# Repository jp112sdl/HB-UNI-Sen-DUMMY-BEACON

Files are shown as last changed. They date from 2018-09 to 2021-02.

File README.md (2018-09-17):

# HB-UNI-Sen-DUMMY-BEACON
**Dummy-Device zum Vermeiden von "Kommunikation gestört"-Servicemeldungen von bis zu 8 inaktiven HomeMatic-Geräten (nur HM-RF, kein HmIP / Wired).**<br/>

Die ist z.B. sehr nützlich bei saisonal verwendeten Geräten, die in Programmen, Diagrammen etc. verwendet, jedoch z.B. in Wintermonaten nicht genutzt werden.
Denn ein Ablernen der Geräte während der Nutzungspausen würde bedeuten, dass Programme nach dem erneuten Anlernen wieder bearbeitet werden müssten.

Es erfolgt:
 - eine automatische Aussendung zyklischer Telegramme an die CCU (bei Sensoren)
 - eine Quittung (Ack) von Steuerbefehlen der CCU (bei Aktoren)
 
_Wird ein Telegramm des "echten" Gerätes empfangen, so wird das Aussenden der Fake-Telegramme automatisch deaktiviert, um Kollisionen / Fehlverhalten zu vermeiden._
 
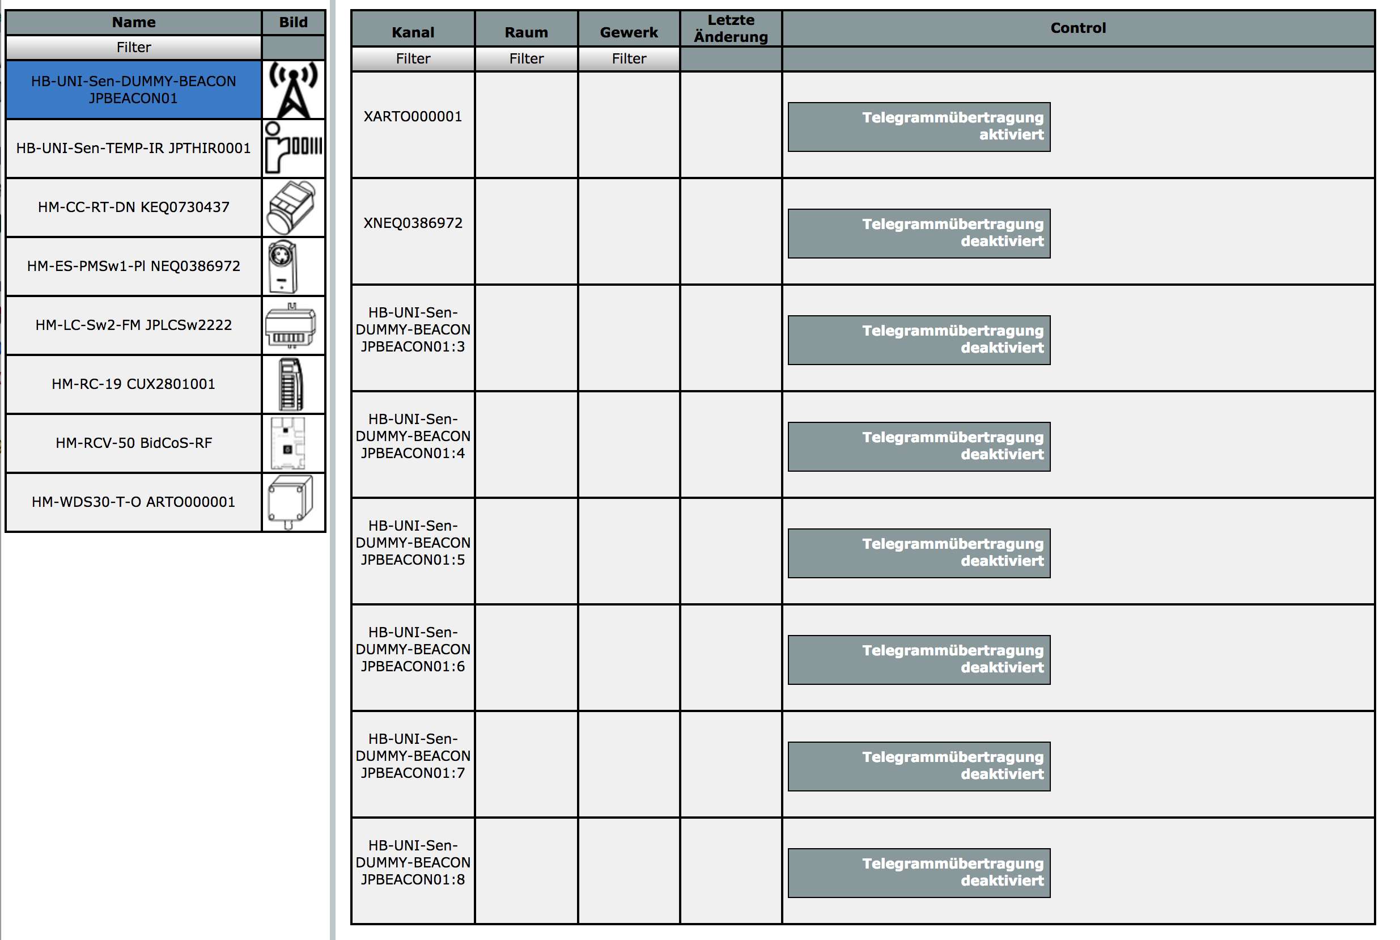
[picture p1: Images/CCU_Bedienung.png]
bedienung
 

## Hardware
### Bauteile
 - 1x Arduino Pro Mini (3.3V 8MHz)
 - 1x CC1101 Funkmodul 868MHz
 - 1x FTDI Adapter
 - 1x Taster
 - 1x Widerstand 330Ohm
 - 1x LED
 
### Verdrahtung
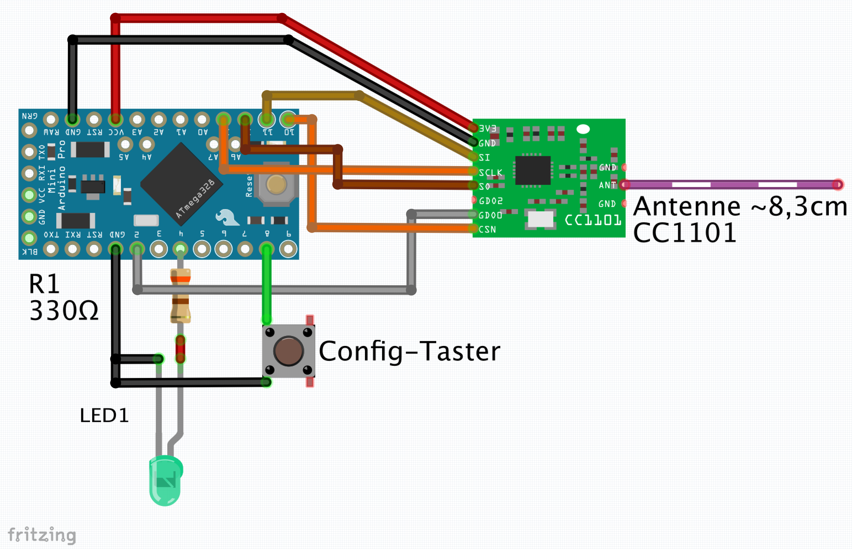
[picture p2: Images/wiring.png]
wiring


Die Stromversorgung erfolgt indealerweise aus einem 5V-Steckernetzteil und wird an **RAW** (+) sowie **GND** (-) des Pro Mini angeschlossen.

## Software
### Arduino IDE
- Arduino IDE [herunterladen](https://www.arduino.cc/en/Main/Software) und installieren
- AskSinPP Bibliothek als [ZIP herunterladen](https://github.com/pa-pa/AskSinPP/archive/master.zip) 
- notwendige Bibliotheken in der Arduino IDE hinzufügen:
  - Sketch -> Bibliothek einbinden -> .ZIP-Bibliothek hinzufügen
    - heruntergeladene AskSinPP Bibliothek ZIP-Datei auswählen
  - Sketch -> Bibliothek einbinden -> Bibliotheken verwalten
    - im Suchfeld folgende Bibliotheken suchen und installieren:
      - EnableInterrupt
      - Low-Power
 - Board einstellen:
   - Board: `Arduino Pro or Pro Mini`
   - Prozessor: `ATmega328P (3.3V, 8 MHz)`
   - Port: `COM-Port` des FTDI Adapters <br>
 - Sketch öffnen. (Die 3 Dateien [HB-UNI-Sen-DUMMY-BEACON.ino](https://raw.githubusercontent.com/jp112sdl/HB-UNI-Sen-DUMMY-BEACON/master/HB-UNI-Sen-DUMMY-BEACON.ino), [HB_Device.h](https://raw.githubusercontent.com/jp112sdl/HB-UNI-Sen-DUMMY-BEACON/master/HB_Device.h) und [HB_MultiChannelDevice.h](https://raw.githubusercontent.com/jp112sdl/HB-UNI-Sen-DUMMY-BEACON/master/HB_MultiChannelDevice.h) müssen sich in einem gemeinsamen Verzeichnis befinden.)
            
- Sketch hochladen:
  - Sketch
    - Hochladen

## HomeMatic
### Addon installieren
Damit das Gerät von der CCU erkannt und unterstützt wird, ist es erforderlich, das [JP-HB-Devices-addon](https://github.com/jp112sdl/JP-HB-Devices-addon) zu installieren.<br/>Es wird **mindestens Version 1.18** benötigt.

### Anlernen an HomeMatic
Das Anlernen erfolgt nach Installation des Addons wie man es von anderen HomeMatic-Geräten gewohnt ist:
- Geräte anlernen -> HM-Gerät anlernen klicken
- **Config-Taster** am Arduino Pro Mini **kurz** drücken
- das neue Gerät erscheint anschließend im Posteingang

### Konfiguration
Damit das Dummy-Device weiß, wessen Telegramme es nun ersetzen soll, müssen die **Adressen** _(Achtung: nicht die Seriennummern!)_ der Geräte im Dummy-Device hinterlegt werden.
<br/>
_Hintergrund-Info: 
Anhand der Seriennummer wird ein HomeMatic Gerät nicht im Funkprotokoll identifiziert. Dies geschieht ausschließlich über die Geräteadresse. Die Adresse (RF_ADDRESS) eines HomeMatic-Geräts ist leider nicht ohne Umwege in der WebUI ersichtlich.
Sie lässt sich beispielsweise als hexadezimalwert dem Device-File im Dateisystem `/etc/config/rfd/<SERIAL.dev>` entnehmen:<br/>

<br/>_

Um das Hinterlegen der gewünschten Adressen weitestgehend zu automatisieren ist wie folgt vorzugehen:<br/><br/>
**1.** In den Geräteeinstellungen des Dummy-Device ist ein Kanal umzubenennen.<br/>
Der Kanalname muss beginnen mit **X** gefolgt von der Seriennummer, des HomeMatic Geräts, das abgebildet werden soll.<br/>
Beispiel:<br/>
 - das HomeMatic-Gerät hat die Seriennummer: **NEQ0386972**
 - der Kanalname des Dummy-Device muss lauten: **XNEQ0386972**

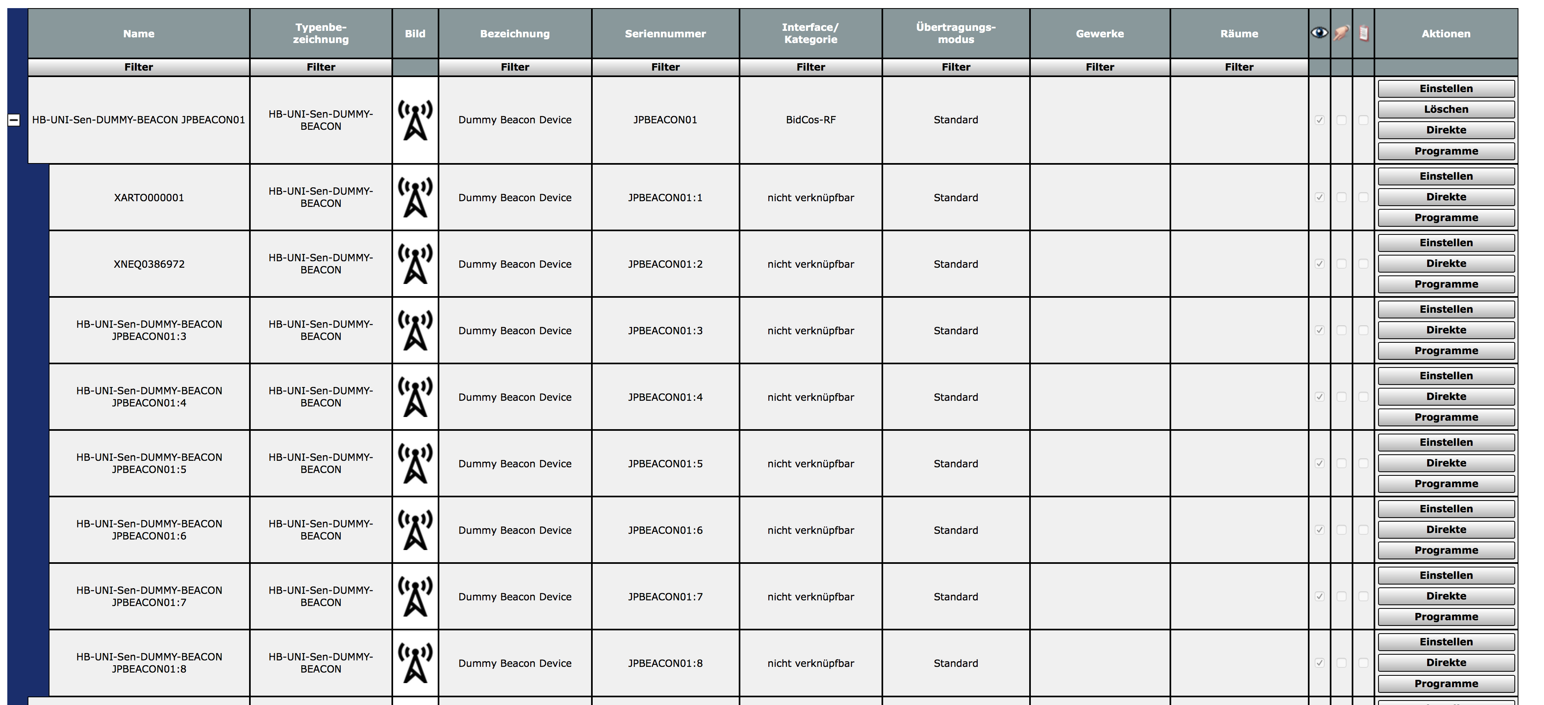
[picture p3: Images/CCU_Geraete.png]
gerate

 <br/>
 
 **2.** Ausführen des [Parametrierungsskripts](https://raw.githubusercontent.com/jp112sdl/HB-UNI-Sen-DUMMY-BEACON/master/additional/ccu_script.txt) auf der CCU.<br/>
(Sollte die Seriennummer des Dummy-Device *nicht* **JPBEACON01** lauten, so ist diese im Skript entpsrechend zu ändern (`string FAKEDEV = "JPBEACON01";`).)
<br/>
Durch Ausführen des Skripts werden nun die Adressen der Geräte ausgelesen und zum Dummy-Device übertragen.

**3.** Einstellungen<br/>
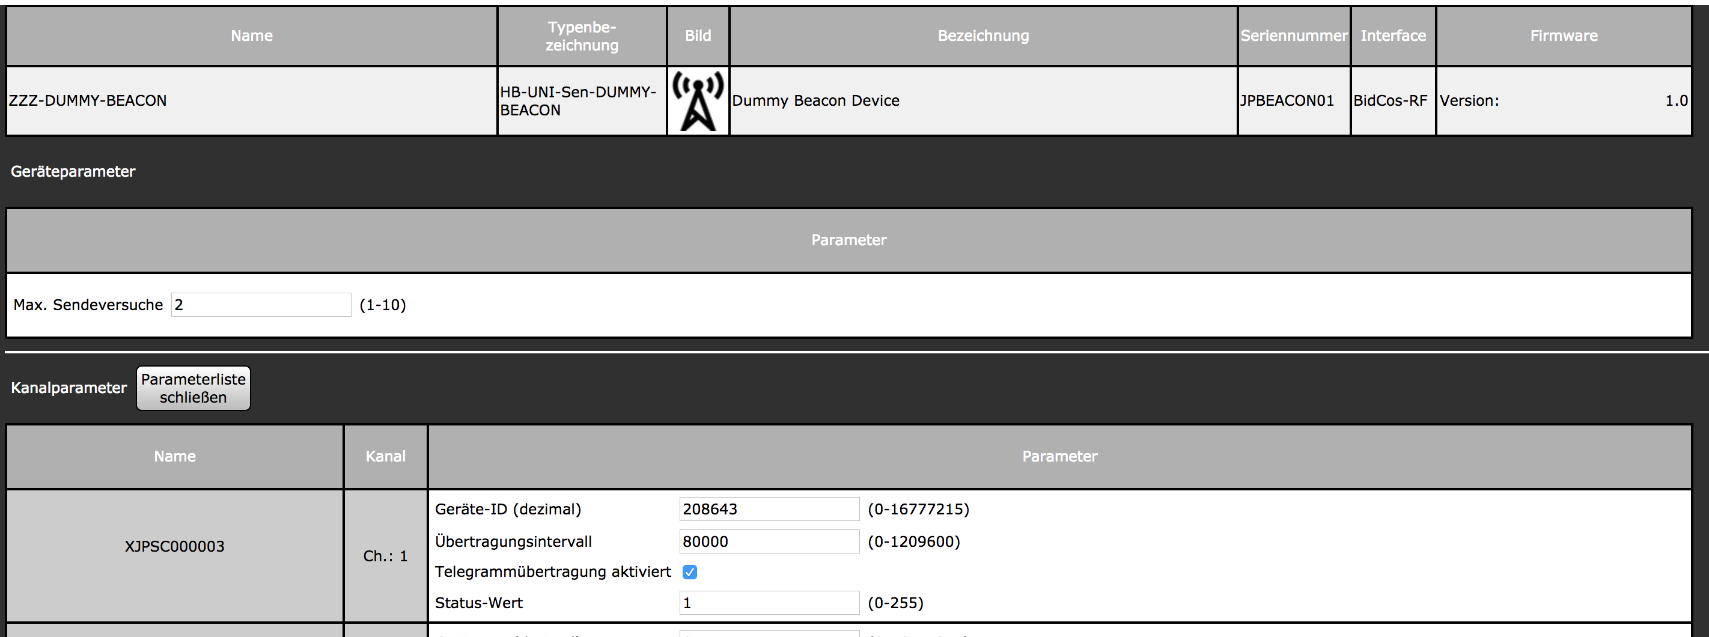
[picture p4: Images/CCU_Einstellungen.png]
einstellungen

<br/>
In den Einstellungen können Parameter
 - für das Gerät
   - Max. Sendeversuche: Anzahl der Sendeversuche bei bidirektionalen Nachrichten
 - je Kanal (also je emuliertem Gerät)
   - Geräte-ID: RF-Adresse; hier dezimal! (wird vom Skript gesetzt)
   - Übertragungsintervall: alle x Sekunden wird ein zyklisches Telegramm gesendet (nur bei Sensoren, bei Aktoren (außer HM-ES-PMSw1-xxx) auf 0 lassen!); die eingegebene Zeit muss kleiner sein als der von HomeMatic erwartete Wert (siehe unten stehende Tabelle)
   - Telegrammübertragung aktiviert: Dummy-Nachrichten werden für dieses Gerät generiert
   - Status-Wert: z.B. bei Fensterkontakt "geschlossen" (0) oder "offen" (1) übertragen
 
 festgelegt werden.

**4.** Betrieb<br/>
Unter "Status und Bedienung"->"Geräte" ist eine Übersicht der aktivierten Kanäle zu sehen.<br/>
bedienung
<br/><br/>
**Achtung:** Der Status der Telegrammübertragung (aktiviert / deaktiviert) muss nicht zwingend der Einstellung wie unter **3.** festgelegt entsprechen!<br/>
Es wird der tatsächliche Status wiedergegeben. Ist z.B. ein Kanal in **3.** aktiviert und es wird jedoch ein Funktelegramm vom "echten" HomeMatic-Gerät empfangen, wird der Kanal in der Übersicht deaktiviert!

**Diese README ist garantiert nicht vollständig! Bei Unklarheiten bitte ein Issue erstellen.**

#### CYCLIC_TIMEOUT Werte der HomeMatic-Geräte:

| Device Type | Timeout | Model ID |
|---|---|---|
| HM-CC-RT-DN | 600 | 0x0095 | 
| HM-CC-RT-DN-BoM | 552 | 0x00bd | 
| HM-CC-SCD | 88200 | 0x0056 | 
| HM-CC-TC | 600 | 0x0039 | 
| HM-CC-VD | 3600 | 0x003a | 
| HM-ES-PMSw1-DR | 600 | 0x00ea | 
| HM-ES-PMSw1-Pl | 600 | 0x00ac | 
| HM-ES-PMSw1-Pl-DN-R1 | 600 | 0x00d7 | 
| HM-ES-PMSw1-Pl-DN-R2 | 600 | 0x00e2 | 
| HM-ES-PMSw1-Pl-DN-R3 | 600 | 0x00e3 | 
| HM-ES-PMSw1-Pl-DN-R4 | 600 | 0x00e4 | 
| HM-ES-PMSw1-Pl-DN-R5 | 600 | 0x00e5 | 
| HM-ES-PMSw1-S | 600 | 0x00f6 | 
| HM-ES-TX-WM | 600 | 0x00de | 
| HM-SCI-3-FM | 88200 | 0x005f | 
| HM-Sec-MDIR | 1200 | 0x004a | 
| HM-Sec-MDIR-2 | 1200 | 0x00c0 | 
| HM-Sec-MDIR-3 | 1200 | 0x00f7 | 
| HM-Sec-RHS | 88200 | 0x0030 | 
| HM-Sec-SC | 88200 | 0x002f | 
| HM-Sec-SC-2 | 88200 | 0x00b1 | 
| HM-Sec-SCo | 10000 | 0x00c7 | 
| HM-Sec-SD | 1209600 | 0x0042 | 
| HM-Sec-SD-2 | 259200 | 0x00aa | 
| HM-Sec-TiS | 88200 | 0x0043 | 
| HM-Sec-WDS | 88200 | 0x0045 | 
| HM-Sec-WDS-2 | 88200 | 0x00b2 | 
| HM-Sen-LI-O | 88200 | 0x00fd | 
| HM-Sen-RD-O | 88200 | 0x00a7 | 
| HM-Sen-Wa-Od | 88200 | 0x009f | 
| HM-TC-IT-WM-W-EU | 600 | 0x00ad | 
| HM-WDS10-TH-O | 600 | 0x003d | 
| HM-WDS100-C6-O | 600 | 0x0040 | 
| HM-WDS100-C6-O-2 | 600 | 0x00ae | 
| HM-WDS20-TH-O | 600 | 0x003c | 
| HM-WDS30-OT2-SM | 40000 | 0x00a8 | 
| HM-WDS30-OT2-SM-2 | 40000 | 0x0102 | 
| HM-WDS30-T-O | 600 | 0x000f | 
| HM-WDS40-TH-I | 600 | 0x003f | 
| HM-WDS40-TH-I-2 | 600 | 0x00bc |

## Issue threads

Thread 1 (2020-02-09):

Fehlermeldungen beim Kompilieren

MathiasJZ, 2020-02-09:
Wenn ich die Firmware bei Arduino-Ide kompiliere bekomme ich immer die gleiche Fehlermeldung:

`Arduino: 1.8.11 (Windows 10), Board: "Arduino Pro or Pro Mini, ATmega328P (3.3V, 8 MHz)

C:\Program Files (x86)\arduino-1.8.11\arduino-builder -dump-prefs -logger=machine -hardware C:\Program Files (x86)\arduino-1.8.11\hardware -hardware C:\Users\mathi\AppData\Local\Arduino15\packages -tools C:\Program Files (x86)\arduino-1.8.11\tools-builder -tools C:\Program Files (x86)\arduino-1.8.11\hardware\tools\avr -tools C:\Users\mathi\AppData\Local\Arduino15\packages -built-in-libraries C:\Program Files (x86)\arduino-1.8.11\libraries -libraries C:\Users\mathi\OneDrive\Documents\Arduino\libraries -fqbn=arduino:avr:pro:cpu=8MHzatmega328 -ide-version=10811 -build-path C:\Users\mathi\AppData\Local\Temp\arduino_build_962732 -warnings=none -build-cache C:\Users\mathi\AppData\Local\Temp\arduino_cache_655553 -prefs=build.warn_data_percentage=75 -prefs=runtime.tools.avr-gcc.path=C:\Program Files (x86)\arduino-1.8.11\hardware\tools\avr -prefs=runtime.tools.avr-gcc-7.3.0-atmel3.6.1-arduino5.path=C:\Program Files (x86)\arduino-1.8.11\hardware\tools\avr -prefs=runtime.tools.arduinoOTA.path=C:\Program Files (x86)\arduino-1.8.11\hardware\tools\avr -prefs=runtime.tools.arduinoOTA-1.3.0.path=C:\Program Files (x86)\arduino-1.8.11\hardware\tools\avr -prefs=runtime.tools.avrdude.path=C:\Program Files (x86)\arduino-1.8.11\hardware\tools\avr -prefs=runtime.tools.avrdude-6.3.0-arduino17.path=C:\Program Files (x86)\arduino-1.8.11\hardware\tools\avr -verbose M:\HB-UNI-Sen-DUMMY-BEACON-master\HB-UNI-Sen-DUMMY-BEACON-master\HB-UNI-Sen-DUMMY-BEACON\HB-UNI-Sen-DUMMY-BEACON.ino
C:\Program Files (x86)\arduino-1.8.11\arduino-builder -compile -logger=machine -hardware C:\Program Files (x86)\arduino-1.8.11\hardware -hardware C:\Users\mathi\AppData\Local\Arduino15\packages -tools C:\Program Files (x86)\arduino-1.8.11\tools-builder -tools C:\Program Files (x86)\arduino-1.8.11\hardware\tools\avr -tools C:\Users\mathi\AppData\Local\Arduino15\packages -built-in-libraries C:\Program Files (x86)\arduino-1.8.11\libraries -libraries C:\Users\mathi\OneDrive\Documents\Arduino\libraries -fqbn=arduino:avr:pro:cpu=8MHzatmega328 -ide-version=10811 -build-path C:\Users\mathi\AppData\Local\Temp\arduino_build_962732 -warnings=none -build-cache C:\Users\mathi\AppData\Local\Temp\arduino_cache_655553 -prefs=build.warn_data_percentage=75 -prefs=runtime.tools.avr-gcc.path=C:\Program Files (x86)\arduino-1.8.11\hardware\tools\avr -prefs=runtime.tools.avr-gcc-7.3.0-atmel3.6.1-arduino5.path=C:\Program Files (x86)\arduino-1.8.11\hardware\tools\avr -prefs=runtime.tools.arduinoOTA.path=C:\Program Files (x86)\arduino-1.8.11\hardware\tools\avr -prefs=runtime.tools.arduinoOTA-1.3.0.path=C:\Program Files (x86)\arduino-1.8.11\hardware\tools\avr -prefs=runtime.tools.avrdude.path=C:\Program Files (x86)\arduino-1.8.11\hardware\tools\avr -prefs=runtime.tools.avrdude-6.3.0-arduino17.path=C:\Program Files (x86)\arduino-1.8.11\hardware\tools\avr -verbose M:\HB-UNI-Sen-DUMMY-BEACON-master\HB-UNI-Sen-DUMMY-BEACON-master\HB-UNI-Sen-DUMMY-BEACON\HB-UNI-Sen-DUMMY-BEACON.ino
Using board 'pro' from platform in folder: C:\Program
Using core 'arduino' from platform in folder: C:\Program
Detecting libraries used...
"C:\\Program Files (x86)\\arduino-1.8.11\\hardware\\tools\\avr/bin/avr-g++" -c -g -Os -w -std=gnu++11 -fpermissive -fno-exceptions -ffunction-sections -fdata-sections -fno-threadsafe-statics -Wno-error=narrowing -flto -w -x c++ -E -CC -mmcu=atmega328p -DF_CPU=8000000L -DARDUINO=10811 -DARDUINO_AVR_PRO -DARDUINO_ARCH_AVR "-IC:\\Program Files (x86)\\arduino-1.8.11\\hardware\\arduino\\avr\\cores\\arduino" "-IC:\\Program Files (x86)\\arduino-1.8.11\\hardware\\arduino\\avr\\variants\\eightanaloginputs" "C:\\Users\\mathi\\AppData\\Local\\Temp\\arduino_build_962732\\sketch\\HB-UNI-Sen-DUMMY-BEACON.ino.cpp" -o nul
Alternatives for EnableInterrupt.h: [EnableInterrupt@0.9.7]
ResolveLibrary(EnableInterrupt.h)
  -> candidates: [EnableInterrupt@0.9.7]
"C:\\Program Files (x86)\\arduino-1.8.11\\hardware\\tools\\avr/bin/avr-g++" -c -g -Os -w -std=gnu++11 -fpermissive -fno-exceptions -ffunction-sections -fdata-sections -fno-threadsafe-statics -Wno-error=narrowing -flto -w -x c++ -E -CC -mmcu=atmega328p -DF_CPU=8000000L -DARDUINO=10811 -DARDUINO_AVR_PRO -DARDUINO_ARCH_AVR "-IC:\\Program Files (x86)\\arduino-1.8.11\\hardware\\arduino\\avr\\cores\\arduino" "-IC:\\Program Files (x86)\\arduino-1.8.11\\hardware\\arduino\\avr\\variants\\eightanaloginputs" "-IC:\\Users\\mathi\\OneDrive\\Documents\\Arduino\\libraries\\EnableInterrupt" "C:\\Users\\mathi\\AppData\\Local\\Temp\\arduino_build_962732\\sketch\\HB-UNI-Sen-DUMMY-BEACON.ino.cpp" -o nul
Alternatives for AskSinPP.h: [AskSinPP-master@4.1.2]
ResolveLibrary(AskSinPP.h)
  -> candidates: [AskSinPP-master@4.1.2]
"C:\\Program Files (x86)\\arduino-1.8.11\\hardware\\tools\\avr/bin/avr-g++" -c -g -Os -w -std=gnu++11 -fpermissive -fno-exceptions -ffunction-sections -fdata-sections -fno-threadsafe-statics -Wno-error=narrowing -flto -w -x c++ -E -CC -mmcu=atmega328p -DF_CPU=8000000L -DARDUINO=10811 -DARDUINO_AVR_PRO -DARDUINO_ARCH_AVR "-IC:\\Program Files (x86)\\arduino-1.8.11\\hardware\\arduino\\avr\\cores\\arduino" "-IC:\\Program Files (x86)\\arduino-1.8.11\\hardware\\arduino\\avr\\variants\\eightanaloginputs" "-IC:\\Users\\mathi\\OneDrive\\Documents\\Arduino\\libraries\\EnableInterrupt" "-IC:\\Users\\mathi\\OneDrive\\Documents\\Arduino\\libraries\\AskSinPP-master" "C:\\Users\\mathi\\AppData\\Local\\Temp\\arduino_build_962732\\sketch\\HB-UNI-Sen-DUMMY-BEACON.ino.cpp" -o nul
Alternatives for LowPower.h: [Low-Power-master@1.6]
ResolveLibrary(LowPower.h)
  -> candidates: [Low-Power-master@1.6]
"C:\\Program Files (x86)\\arduino-1.8.11\\hardware\\tools\\avr/bin/avr-g++" -c -g -Os -w -std=gnu++11 -fpermissive -fno-exceptions -ffunction-sections -fdata-sections -fno-threadsafe-statics -Wno-error=narrowing -flto -w -x c++ -E -CC -mmcu=atmega328p -DF_CPU=8000000L -DARDUINO=10811 -DARDUINO_AVR_PRO -DARDUINO_ARCH_AVR "-IC:\\Program Files (x86)\\arduino-1.8.11\\hardware\\arduino\\avr\\cores\\arduino" "-IC:\\Program Files (x86)\\arduino-1.8.11\\hardware\\arduino\\avr\\variants\\eightanaloginputs" "-IC:\\Users\\mathi\\OneDrive\\Documents\\Arduino\\libraries\\EnableInterrupt" "-IC:\\Users\\mathi\\OneDrive\\Documents\\Arduino\\libraries\\AskSinPP-master" "-IC:\\Users\\mathi\\OneDrive\\Documents\\Arduino\\libraries\\Low-Power-master" "C:\\Users\\mathi\\AppData\\Local\\Temp\\arduino_build_962732\\sketch\\HB-UNI-Sen-DUMMY-BEACON.ino.cpp" -o nul
"C:\\Program Files (x86)\\arduino-1.8.11\\hardware\\tools\\avr/bin/avr-g++" -c -g -Os -w -std=gnu++11 -fpermissive -fno-exceptions -ffunction-sections -fdata-sections -fno-threadsafe-statics -Wno-error=narrowing -flto -w -x c++ -E -CC -mmcu=atmega328p -DF_CPU=8000000L -DARDUINO=10811 -DARDUINO_AVR_PRO -DARDUINO_ARCH_AVR "-IC:\\Program Files (x86)\\arduino-1.8.11\\hardware\\arduino\\avr\\cores\\arduino" "-IC:\\Program Files (x86)\\arduino-1.8.11\\hardware\\arduino\\avr\\variants\\eightanaloginputs" "-IC:\\Users\\mathi\\OneDrive\\Documents\\Arduino\\libraries\\EnableInterrupt" "-IC:\\Users\\mathi\\OneDrive\\Documents\\Arduino\\libraries\\AskSinPP-master" "-IC:\\Users\\mathi\\OneDrive\\Documents\\Arduino\\libraries\\Low-Power-master" "C:\\Users\\mathi\\OneDrive\\Documents\\Arduino\\libraries\\AskSinPP-master\\AlarmClock.cpp" -o nul
"C:\\Program Files (x86)\\arduino-1.8.11\\hardware\\tools\\avr/bin/avr-g++" -c -g -Os -w -std=gnu++11 -fpermissive -fno-exceptions -ffunction-sections -fdata-sections -fno-threadsafe-statics -Wno-error=narrowing -flto -w -x c++ -E -CC -mmcu=atmega328p -DF_CPU=8000000L -DARDUINO=10811 -DARDUINO_AVR_PRO -DARDUINO_ARCH_AVR "-IC:\\Program Files (x86)\\arduino-1.8.11\\hardware\\arduino\\avr\\cores\\arduino" "-IC:\\Program Files (x86)\\arduino-1.8.11\\hardware\\arduino\\avr\\variants\\eightanaloginputs" "-IC:\\Users\\mathi\\OneDrive\\Documents\\Arduino\\libraries\\EnableInterrupt" "-IC:\\Users\\mathi\\OneDrive\\Documents\\Arduino\\libraries\\AskSinPP-master" "-IC:\\Users\\mathi\\OneDrive\\Documents\\Arduino\\libraries\\Low-Power-master" "C:\\Users\\mathi\\OneDrive\\Documents\\Arduino\\libraries\\AskSinPP-master\\Globals.cpp" -o nul
"C:\\Program Files (x86)\\arduino-1.8.11\\hardware\\tools\\avr/bin/avr-g++" -c -g -Os -w -std=gnu++11 -fpermissive -fno-exceptions -ffunction-sections -fdata-sections -fno-threadsafe-statics -Wno-error=narrowing -flto -w -x c++ -E -CC -mmcu=atmega328p -DF_CPU=8000000L -DARDUINO=10811 -DARDUINO_AVR_PRO -DARDUINO_ARCH_AVR "-IC:\\Program Files (x86)\\arduino-1.8.11\\hardware\\arduino\\avr\\cores\\arduino" "-IC:\\Program Files (x86)\\arduino-1.8.11\\hardware\\arduino\\avr\\variants\\eightanaloginputs" "-IC:\\Users\\mathi\\OneDrive\\Documents\\Arduino\\libraries\\EnableInterrupt" "-IC:\\Users\\mathi\\OneDrive\\Documents\\Arduino\\libraries\\AskSinPP-master" "-IC:\\Users\\mathi\\OneDrive\\Documents\\Arduino\\libraries\\Low-Power-master" "C:\\Users\\mathi\\OneDrive\\Documents\\Arduino\\libraries\\AskSinPP-master\\HMID.cpp" -o nul
"C:\\Program Files (x86)\\arduino-1.8.11\\hardware\\tools\\avr/bin/avr-g++" -c -g -Os -w -std=gnu++11 -fpermissive -fno-exceptions -ffunction-sections -fdata-sections -fno-threadsafe-statics -Wno-error=narrowing -flto -w -x c++ -E -CC -mmcu=atmega328p -DF_CPU=8000000L -DARDUINO=10811 -DARDUINO_AVR_PRO -DARDUINO_ARCH_AVR "-IC:\\Program Files (x86)\\arduino-1.8.11\\hardware\\arduino\\avr\\cores\\arduino" "-IC:\\Program Files (x86)\\arduino-1.8.11\\hardware\\arduino\\avr\\variants\\eightanaloginputs" "-IC:\\Users\\mathi\\OneDrive\\Documents\\Arduino\\libraries\\EnableInterrupt" "-IC:\\Users\\mathi\\OneDrive\\Documents\\Arduino\\libraries\\AskSinPP-master" "-IC:\\Users\\mathi\\OneDrive\\Documents\\Arduino\\libraries\\Low-Power-master" "C:\\Users\\mathi\\OneDrive\\Documents\\Arduino\\libraries\\AskSinPP-master\\Led.cpp" -o nul
"C:\\Program Files (x86)\\arduino-1.8.11\\hardware\\tools\\avr/bin/avr-g++" -c -g -Os -w -std=gnu++11 -fpermissive -fno-exceptions -ffunction-sections -fdata-sections -fno-threadsafe-statics -Wno-error=narrowing -flto -w -x c++ -E -CC -mmcu=atmega328p -DF_CPU=8000000L -DARDUINO=10811 -DARDUINO_AVR_PRO -DARDUINO_ARCH_AVR "-IC:\\Program Files (x86)\\arduino-1.8.11\\hardware\\arduino\\avr\\cores\\arduino" "-IC:\\Program Files (x86)\\arduino-1.8.11\\hardware\\arduino\\avr\\variants\\eightanaloginputs" "-IC:\\Users\\mathi\\OneDrive\\Documents\\Arduino\\libraries\\EnableInterrupt" "-IC:\\Users\\mathi\\OneDrive\\Documents\\Arduino\\libraries\\AskSinPP-master" "-IC:\\Users\\mathi\\OneDrive\\Documents\\Arduino\\libraries\\Low-Power-master" "C:\\Users\\mathi\\OneDrive\\Documents\\Arduino\\libraries\\AskSinPP-master\\PhaseCut.cpp" -o nul
"C:\\Program Files (x86)\\arduino-1.8.11\\hardware\\tools\\avr/bin/avr-g++" -c -g -Os -w -std=gnu++11 -fpermissive -fno-exceptions -ffunction-sections -fdata-sections -fno-threadsafe-statics -Wno-error=narrowing -flto -w -x c++ -E -CC -mmcu=atmega328p -DF_CPU=8000000L -DARDUINO=10811 -DARDUINO_AVR_PRO -DARDUINO_ARCH_AVR "-IC:\\Program Files (x86)\\arduino-1.8.11\\hardware\\arduino\\avr\\cores\\arduino" "-IC:\\Program Files (x86)\\arduino-1.8.11\\hardware\\arduino\\avr\\variants\\eightanaloginputs" "-IC:\\Users\\mathi\\OneDrive\\Documents\\Arduino\\libraries\\EnableInterrupt" "-IC:\\Users\\mathi\\OneDrive\\Documents\\Arduino\\libraries\\AskSinPP-master" "-IC:\\Users\\mathi\\OneDrive\\Documents\\Arduino\\libraries\\Low-Power-master" "C:\\Users\\mathi\\OneDrive\\Documents\\Arduino\\libraries\\AskSinPP-master\\aes128_dec.cpp" -o nul
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

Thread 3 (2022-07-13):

Device mit mehreren channels

kmbach, 2022-07-13:
Hallo, super Idee! Habe die Hard- und Software problemlos installiert.
Mein Problem:
Ich möchte einen Fenstersensor "ZEL STG RM FFK" (entspricht dem  HM-Sec-SC) damit emulieren. Dieser hat einen Sabotagekontakt der natürlich anspricht, wenn ich die Batterie aus dem Sensor entferne.
Wie läßt sich ein gesczlossener Sabotagekontakt emulieren?
Vielen Dank!
Gruß kmbach

jp112sdl, 2022-07-13:
Vollständige (Info)Messages der verschiedenen Geräte sind nicht vorgesehen

Am einfachsten wäre es, du schließt den Sabotagekontakt mit einem spitzen Gegenstand und nimmst dann die Batterien raus.

kmbach, 2022-08-20:
Vielen Dank für die Info! Das reicht co natürlich aus.

Closed 2022-08-20.

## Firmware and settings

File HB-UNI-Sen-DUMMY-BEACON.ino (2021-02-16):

//- -----------------------------------------------------------------------------------------------------------------------
// AskSin++
// 2016-10-31 papa Creative Commons - http://creativecommons.org/licenses/by-nc-sa/3.0/de/
// 2018-08-30 jp112sdl Creative Commons - http://creativecommons.org/licenses/by-nc-sa/3.0/de/
//- -----------------------------------------------------------------------------------------------------------------------
// compatible to AskSinPP commit b4f6000
// ci-test=yes board=328p aes=no

#define MAX_FAKEDEVICE_COUNT  8

#define EI_NOTEXTERNAL
#include <EnableInterrupt.h>
#include <AskSinPP.h>
#include <LowPower.h>
#include <Register.h>

#define SYS_LED_PIN        4
#define OK_LED_PIN         5
#define ERROR_LED_PIN      6

using namespace as;

struct FakeDeviceInfo {
  HMID FakeDeviceID;

  // known timeouts
  // 552, 600, 1200, 3600, 10000, 259200, 40000, 88200, 259200, 1209600
  uint32_t CyclicTimeout;

  bool     Enabled;
  uint32_t CurrentTick;
};

FakeDeviceInfo fakeDevice[MAX_FAKEDEVICE_COUNT];
StatusLed<ERROR_LED_PIN>  errorLed;
#include "HB_MultiChannelDevice.h"
#define CONFIG_BUTTON_PIN  8
#define PEERS_PER_CHANNEL  1
#define CYCLIC_MSG_TIMEOUT 3600  // seconds between sending information about en-/disabled fake devices to ccu

// define all device properties
const struct DeviceInfo PROGMEM devinfo = {
  {0xF3, 0xFF, 0x00},          // Device ID
  "JPBEACON00",                // Device Serial
  {0xF3, 0xFF},                // Device Model
  0x10,                        // Firmware Version
  0x53,                        // Device Type
  {0x01, 0x01}                 // Info Bytes
};

typedef AskSin<StatusLed<SYS_LED_PIN>, NoBattery, Radio<AvrSPI<10, 11, 12, 13>, 2> > Hal;
Hal hal;
StatusLed<OK_LED_PIN> okLed;

DEFREGISTER(UReg0, MASTERID_REGS, DREG_TRANSMITTRYMAX)
class UList0 : public RegList0<UReg0> {
  public:
    UList0 (uint16_t addr) : RegList0<UReg0>(addr) {}
    void defaults () {
      clear();
      transmitDevTryMax(2);
    }
};

DEFREGISTER(UReg1, 0x01, 0x02, 0x03, 0x04, 0x05, 0x06, 0x07, 0x08)
class UList1 : public RegList1<UReg1> {
  public:
    UList1 (uint32_t addr) : RegList1<UReg1>(addr) {}

    bool FakeDeviceID (HMID value) const {
      uint8_t v[3];
      memcpy(v, &value, 3);
      return this->writeRegister(0x01, v[0] & 0xff) && this->writeRegister(0x02, v[1] & 0xff) && this->writeRegister(0x03, v[2] & 0xff);
    }

    HMID FakeDeviceID () const {
      return { this->readRegister(0x01, 0), this->readRegister(0x02, 0), this->readRegister(0x03, 0) };
    }

    bool CyclicTimeout (uint32_t value) const {
      return this->writeRegister(0x04, (value >> 16) & 0xff) && this->writeRegister(0x05, (value >> 8) & 0xff) && this->writeRegister(0x06, value & 0xff);
    }
    uint32_t CyclicTimeout () const {
      return ((uint32_t)this->readRegister(0x04, 0) << 16) | ((uint32_t)this->readRegister(0x05, 0) << 8) | (uint32_t)this->readRegister(0x06, 0);
    }

    bool FakeDeviceEnabled () const {
      return this->readBit(0x07, 0, true);
    }
    bool FakeDeviceEnabled (bool v) const {
      return this->writeBit(0x07, 0, v);
    }

    bool StatusValue (uint8_t value) const {
      return this->writeRegister(0x08, value & 0xff);
    }
    uint8_t StatusValue () const {
      return this->readRegister(0x08, 0);
    }

    void defaults () {
      clear();
      FakeDeviceID({0x00, 0x00, 0x00});
      CyclicTimeout(0);
      FakeDeviceEnabled(false);
      StatusValue(0);
    }
};

class DummyDeviceEventMsg : public Message {
  public:
    void init(uint8_t msgcnt, uint8_t channel, bool enabled) {
      Message::init(0x0b, msgcnt, 0x53, BCAST , channel, enabled);
    }
};

class FakeChannel : public Channel<Hal, UList1, EmptyList, List4, PEERS_PER_CHANNEL, UList0>, public Alarm {
    DummyDeviceEventMsg   dmsg;

  private:
    uint16_t  _current_tick;
    bool      _last_enabled;

  public:

    FakeChannel () : Channel(), Alarm(0), _current_tick(0), _last_enabled(false) {}
    virtual ~FakeChannel () {}

    virtual void trigger (__attribute__ ((unused)) AlarmClock& clock) {
      set(seconds2ticks(1));


      uint8_t devIdx = number() - 1;

      HMID fakeDevId = fakeDevice[devIdx].FakeDeviceID;

      if (fakeDevId.valid() && fakeDevice[devIdx].Enabled == true) {
        if (fakeDevice[devIdx].CyclicTimeout > 0) {
          fakeDevice[devIdx].CurrentTick++;
          if (fakeDevice[devIdx].CurrentTick >= fakeDevice[devIdx].CyclicTimeout) {
            okLed.ledOn(millis2ticks(200));
            DPRINT(F("SEND MSG FOR DEV ")); fakeDevId.dump(); DPRINTLN("");
            device().sendFakeInfoActuatorStatus(fakeDevId, device().nextcount(), *this);
            fakeDevice[devIdx].CurrentTick = 0;
            _delay_ms(200);
          }
        }
      }

      if (_current_tick >= CYCLIC_MSG_TIMEOUT || _current_tick == 0 || _last_enabled != fakeDevice[devIdx].Enabled) {
        DPRINT(F("ch ")); DDEC(number()); DPRINTLN(F(", BROADCASTING OWN MSG"));
        dmsg.init(device().nextcount(), number(), fakeDevice[devIdx].Enabled);
        device().broadcastPeerEvent(dmsg, *this);
        _delay_ms(200);
        _current_tick = 0;
      }

      _current_tick++;
      _last_enabled = fakeDevice[devIdx].Enabled;
      sysclock.add(*this);
    }

    void configChanged() {
      HMID fdev = this->getList1().FakeDeviceID();
      DPRINT(F("ch ")); DDEC(number()); DPRINT(F(", FakeDeviceID = ")); fdev.dump();  DPRINT(F(", Enabled = ")); DDEC(this->getList1().FakeDeviceEnabled()); DPRINT(F(", CyclicTimeout = ")); DDECLN( this->getList1().CyclicTimeout());
      uint32_t timeout = this->getList1().CyclicTimeout();
      fakeDevice[number() - 1] = { fdev, timeout, this->getList1().FakeDeviceEnabled(), (timeout > 10) ? timeout - 10 : 0 };
    }

    void setup(Device<Hal, UList0>* dev, uint8_t number, uint16_t addr) {
      Channel::setup(dev, number, addr);

      sysclock.add(*this);
    }

    uint8_t status () const {
      return this->getList1().StatusValue();
    }

    uint8_t flags () const {
      return 0;
    }
};


typedef MultiChannelDevice<Hal, FakeChannel, MAX_FAKEDEVICE_COUNT, UList0> UType;
UType sdev(devinfo, 0x20);
ConfigButton<UType> cfgBtn(sdev);

void setup () {
  DINIT(57600, ASKSIN_PLUS_PLUS_IDENTIFIER);
  sdev.init(hal);
  buttonISR(cfgBtn, CONFIG_BUTTON_PIN);
  okLed.init();
  errorLed.init();
  sdev.initDone();
}

void loop() {
  bool worked = hal.runready();
  bool poll = sdev.pollRadio();
  if ( worked == false && poll == false ) {
    //hal.activity.savePower<Idle<>>(hal);
  }
}

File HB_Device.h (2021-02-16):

//- -----------------------------------------------------------------------------------------------------------------------
// AskSin++
// 2016-10-31 papa Creative Commons - http://creativecommons.org/licenses/by-nc-sa/3.0/de/
// 2018-09-03 jp112sdl Creative Commons - http://creativecommons.org/licenses/by-nc-sa/3.0/de/
//- -----------------------------------------------------------------------------------------------------------------------

#ifndef __DEVICE_H__
#define __DEVICE_H__

#include "AskSinPP.h"
#include "Sign.h"
#include "HMID.h"
#include "Channel.h"
#include "ChannelList.h"
#include "Message.h"
#include "Radio.h"
#include "Led.h"
#include "Activity.h"

#define OTA_CONFIG_START 0x7fe0 // start address of 16 byte config data in bootloader
#define OTA_MODEL_START  0x7ff0 // start address of 2 byte model id in bootloader
#define OTA_SERIAL_START 0x7ff2 // start address of 10 byte serial number in bootloader
#define OTA_HMID_START   0x7ffc // start address of 3 byte device id in bootloader

namespace as {

struct DeviceInfo {
  uint8_t DeviceID[3];
  char    Serial[11];
  uint8_t DeviceModel[2];
  uint8_t Firmware;
  uint8_t DeviceType;
  uint8_t DeviceInfo[2];
};

template <class HalType, class List0Type = List0>
class Device {

  public:
    typedef typename HalType::LedType LedType;
    typedef typename HalType::BatteryType BatteryType;
    typedef typename HalType::RadioType RadioType;

  private:
    HalType* hal;
    List0Type&   list0;
    uint8_t  msgcount;

    HMID    lastdev;
    uint8_t lastmsg;

#ifdef USE_HW_SERIAL
    uint8_t device_id[3] = { 0x00, 0x00, 0x00 };
#endif

  protected:
    Message     msg;
    KeyStore    kstore;

    const DeviceInfo& info;
    uint8_t      numChannels;

  public:
    Device (const DeviceInfo& i, uint16_t addr, List0Type& l, uint8_t ch) : hal(0), list0(l), msgcount(0), lastmsg(0), kstore(addr), info(i), numChannels(ch) {}
    virtual ~Device () {}

    LedType& led ()  {
      return hal->led;
    }
    BatteryType& battery ()  {
      return hal->battery;
    }
    const BatteryType& battery () const {
      return hal->battery;
    }
    RadioType& radio () {
      return hal->radio;
    }
    KeyStore& keystore () {
      return this->kstore;
    }
    Activity& activity () {
      return hal->activity;
    }

    Message& message () {
      return msg;
    }

    void channels (uint8_t num) {
      numChannels = num;
    }

    uint8_t channels () const {
      return numChannels;
    }

    bool hasChannel (uint8_t number) const {
      return number != 0 && number <= channels();
    }


    bool isRepeat(const Message& m) {
      if ( m.isRepeated() && lastdev == m.from() && lastmsg == m.count() ) {
        return true;
      }
      // store last message data
      lastdev = m.from();
      lastmsg = m.count();
      return false;
    }

    void setHal (HalType& h) {
      hal = &h;
    }

    uint8_t getConfigByte (uint8_t offset) {
      uint8_t data = 0;
#ifdef USE_OTA_BOOTLOADER
      if ( offset < 16 ) {
        HalType::pgm_read(&data, OTA_CONFIG_START + offset, 1);
      }
#elif defined(DEVICE_CONFIG)
      uint8_t tmp[] = {DEVICE_CONFIG};
      if ( offset < sizeof(tmp) ) {
        data = tmp[offset];
      }
#endif
      return data;
    }

    void getDeviceID (HMID& id) {
      uint8_t ids[3];
      memcpy_P(ids, info.DeviceID, 3);
      id = HMID(ids);
    }

    void getDeviceSerial (uint8_t* serial) {
      memcpy_P(serial, info.Serial, 10);
    }

    bool isDeviceSerial (const uint8_t* serial) {
      uint8_t tmp[10];
      getDeviceSerial(tmp);
      return memcmp(serial, tmp, 10) == 0;
    }

    bool isDeviceID(const HMID& id) {
      HMID me;
      getDeviceID(me);
      return id == me;
    }

    void getDeviceModel (uint8_t* model) {
#ifdef USE_OTA_BOOTLOADER
      HalType::pgm_read(model, OTA_MODEL_START, 2);
#else
      memcpy_P(model, info.DeviceModel, sizeof(info.DeviceModel));
#endif
    }

    void getDeviceInfo (uint8_t* di) {
      // first byte is number of channels
      *di = this->channels();
      memcpy_P(di + 1, info.DeviceInfo, sizeof(info.DeviceInfo));
    }

    HMID getMasterID () {
      return list0.masterid();
    }

    const List0Type& getList0 () {
      return list0;
    }

    bool pollRadio () {
      uint8_t num = radio().read(msg);
      // minimal msg is 10 byte
      // ignore own messages from radio
      if ( num >= 10 && isDeviceID(msg.from()) == false ) {
        return process(msg);
      }
      return false;
    }

    uint8_t nextcount () {
      return ++msgcount;
    }

    virtual void configChanged () {}

    virtual bool process(__attribute__((unused)) Message& msg) {
      return false;
    }

    bool isBroadcastMsg(Message msg) {
      return (msg.to() == HMID::broadcast && msg.isPairSerial()) || ( msg.isBroadcast() && (msg.isRemoteEvent() || msg.isSensorEvent()) );
    }

    bool sendFake(Message& msg, const HMID& from) {
      msg.to(getMasterID());
      if ( msg.to().valid() == true ) {
        msg.from(from);
        msg.setRpten(); // has to be set always
        return send(msg);
      } else {
        DPRINTLN("NO VALID RECEIVER (Central) DEFINED");
        return true;
      }
    }

    bool send(Message& msg, const HMID& to) {
      msg.to(to);
      getDeviceID(msg.from());
      msg.setRpten(); // has to be set always
      return send(msg);
    }

    bool send(Message& msg) {
      bool result = false;
      uint8_t maxsend = list0.transmitDevTryMax();
      led().set(LedStates::send);
      while ( result == false && maxsend > 0 ) {
        result = radio().write(msg, msg.burstRequired());
        DPRINT(F("<- "));
        msg.dump();
        maxsend--;
        if ( result == true && msg.ackRequired() == true && msg.to().valid() == true ) {
          Message response;
          if ( (result = waitResponse(msg, response, 60)) ) { // 600ms
#ifdef USE_AES
            if ( response.isChallengeAes() == true ) {
              AesChallengeMsg& cm = response.aesChallenge();
              result = processChallenge(msg, cm.challenge(), cm.keyindex());
            }
            else
#endif
            {
              result = response.isAck();
              // if we got a Nack - we stop trying to send again
              if ( response.isNack() ) {
                maxsend = 0;
              }
              // we request wakeup
              // we got the flag to stay awake
              if ( msg.isWakeMeUp() || response.isKeepAwake() ) {
                activity().stayAwake(millis2ticks(500));
              }
            }
          }
          DPRINT(F("waitAck: ")); DHEX((uint8_t)result); DPRINTLN(F(""));
        }
      }
      if ( result == true ) led().set(LedStates::ack);
      else led().set(LedStates::nack);
      return result;
    }


    void sendAck (Message& msg, uint8_t flag = 0x00) {
      msg.ack().init(flag);
      kstore.addAuth(msg);
      send(msg, msg.from());
    }
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

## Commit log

2018-09-03 changed deviceId disabling behaviour when detecting alive device
2018-09-03 added images
    [wiring.fzz]
2018-09-14 added some led stuff
2018-09-17 some structural changes for LEDs
